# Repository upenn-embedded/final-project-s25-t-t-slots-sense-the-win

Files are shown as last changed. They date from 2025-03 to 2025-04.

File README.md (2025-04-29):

Review Assignment Due Date (https://classroom.github.com/a/WXeqVgks)

# final-project-skeleton

* Team Number: 6
* Team Name: T&T Slots - Sense the Win
* Team Members: Theodor Bulacovschi, Yiding Tian
* GitHub Repository URL: [https://github.com/upenn-embedded/final-project-s25-t-t-slots-sense-the-win](https://github.com/upenn-embedded/final-project-s25-t-t-slots-sense-the-win)
* GitHub Pages Website URL: [for final submission]

## Final Project Proposal

### 1. Abstract

*In a few sentences, describe your final project.*

Our project is an interactive chance-based gaming device that takes into account the player's vital signs to adjust the probability of winning, maximizing engagement and retention. In lay-man's terms, it's a slot machine that measures the user's pulse and changes the odds to keep them playing longer.

### 2. Motivation

*What is the problem that you are trying to solve? Why is this project interesting? What is the intended purpose?*

Considering the abundance of health-tracking initiatives, we thought of making a unique device, merging entertainment and bio-monitoring. This device would also be useful as a case study for the efficiency of variable-odds gaming devices, and the effects on the users.

### 3. System Block Diagram

*Show your high level design, as done in WS1 and WS2. What are the critical components in your system? How do they communicate (I2C?, interrupts, ADC, etc.)? What power regulation do you need?*

Motors for actual slot machine wheels are optional, and they would require extra power beyond what the AtMega can provide. However, their implementation would not be that difficult, considering the power circuitry already identified for WS1.

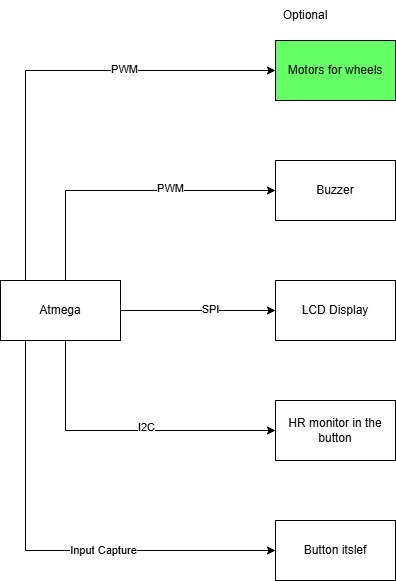
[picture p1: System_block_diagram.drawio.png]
Diagram


### 4. Design Sketches

*What will your project look like? Do you have any critical design features? Will you need any special manufacturing techniques to achieve your vision, like power tools, laser cutting, or 3D printing?*

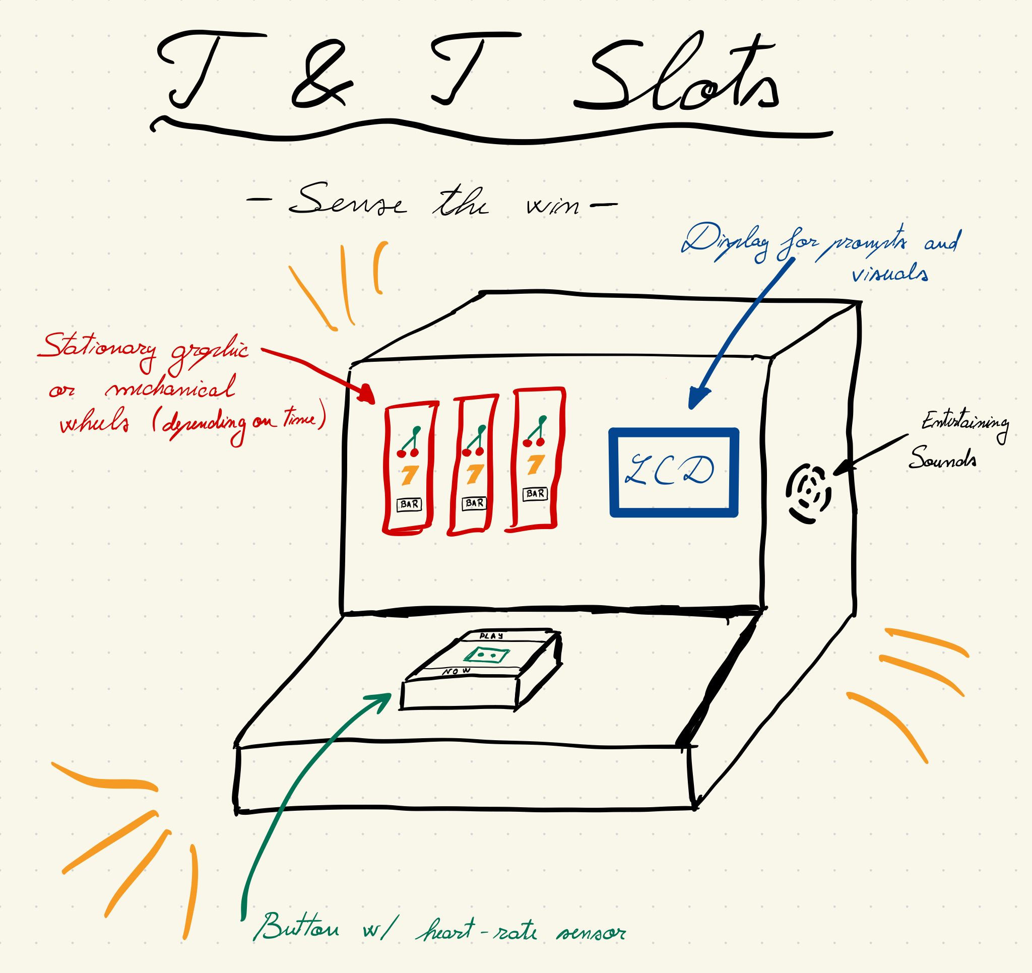
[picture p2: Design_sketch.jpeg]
Design_sketch


### 5. Software Requirements Specification (SRS)

*Formulate key software requirements here. Think deeply on the design: What must your device do? How will you measure this during validation testing? Create 4 to 8 critical system requirements.*

*These must be testable! See the Final Project Manual Appendix for details. Refer to the table below; replace these examples with your own.*

**5.1 Definitions, Abbreviations**

Here, you will define any special terms, acronyms, or abbreviations you plan to use for hardware

HR - heart rate

**5.2 Functionality**

| ID | Description |
| --- | --- |
| SRS-01 | The ATmega shall continuously prompt the user to play, telling them to keep their hand pressing the button until the HR sensor establishes their pulse. |
| SRS-02 | The HR sensor shall be measuring only while the button is pressed, to conceal its existance. |
| SRS-03 | Upon button release, the ATmega shall change the odds in the following manner: if the HR is low, increase odds of winning to increase excitement, HR, and engagement. If HR is high, decrease odds to elongate play, build anticipation, and increase profits. |
| SRS-04 | The buzzer shall play varied exciting tunes, encouraging continued play, and shall react to game outcomes. |
| SRS-05 | If implemented, the wheels should begin spinning on button press, and sequentially stop after the button release, according to the game outcome. |

### 6. Hardware Requirements Specification (HRS)

*Formulate key hardware requirements here. Think deeply on the design: What must your device do? How will you measure this during validation testing? Create 4 to 8 critical system requirements.*

*These must be testable! See the Final Project Manual Appendix for details. Refer to the table below; replace these examples with your own.*

**6.1 Definitions, Abbreviations**

Here, you will define any special terms, acronyms, or abbreviations you plan to use for hardware

**6.2 Functionality**

| ID | Description |
| --- | --- |
| HRS-01 | A heart rate monitor shall be used for monitoring user vital signs. It should be able to measure HR in the range 50-180 BPM. |
| HRS-02 | A buzzer shall be able play various sound frequencies and patterns in a pleasant manner. |
| HRS-03 | A display shall be able to display prompts, information and potentially animations to the user. |
| HRS-04 | A button shall be made big enough to conceal the HR sensor, while being transparent in the region required for measurements. |
| HRS-05 | If implemented, the motors spinning the slot wheels should have variable speed, make the clicking sounds specific to slot machines, and be able to stop at precises positions according to the game outcome. |

### 7. Bill of Materials (BOM)

*What major components do you need and why? Try to be as specific as possible. Your Hardware & Software Requirements Specifications should inform your component choices.*

*In addition to this written response, copy the Final Project BOM Google Sheet and fill it out with your critical components (think: processors, sensors, actuators). Include the link to your BOM in this section.*

[https://docs.google.com/spreadsheets/d/1qyvZnWI3Nq7rkF-FLIlKeIRL2Z1_xs5uF36gUQWZ2QY/edit?usp=sharing](https://docs.google.com/spreadsheets/d/1qyvZnWI3Nq7rkF-FLIlKeIRL2Z1_xs5uF36gUQWZ2QY/edit?usp=sharing)

### 8. Final Demo Goals

*How will you demonstrate your device on demo day? Will it be strapped to a person, mounted on a bicycle, require outdoor space? Think of any physical, temporal, and other constraints that could affect your planning.*

It will be on a table. We will have well-rested (calm heart rate) players play, then do jumping jacks to elevate the players heart rate and see the different effects on the outcomes of the slot machine.

### 9. Sprint Planning

*You've got limited time to get this project done! How will you plan your sprint milestones? How will you distribute the work within your team? Review the schedule in the final project manual for exact dates.*

| Milestone  | Functionality Achieved | Distribution of Work |
| --- | --- | --- |
| Sprint #1  | Display prompts on LCD | 50%, details TBD |
| Sprint #2  | Communicate over I2C with HR sensor | 50%, details TBD |
| MVP Demo | Continuous HR values, Display game outcomes | 50%, details TBD |
| Final Demo | HR monitor only when button is pressed, variable odds, animations, sound | 50%, details TBD |

**This is the end of the Project Proposal section. The remaining sections will be filled out based on the milestone schedule.**

## Sprint Review #1

### Last week's progress
Just Started

### Current state of project
Wrote code for displaying prompts. Implemented the basic game stages and state machine. Designed GUI for the game. Drew animations on screen. 
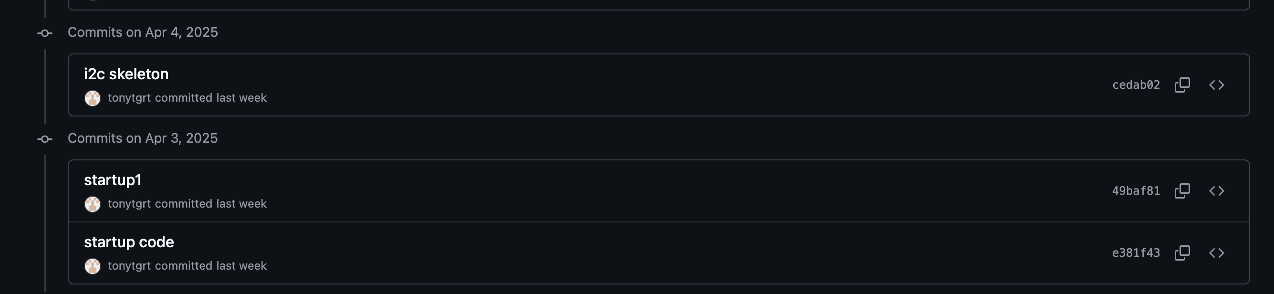
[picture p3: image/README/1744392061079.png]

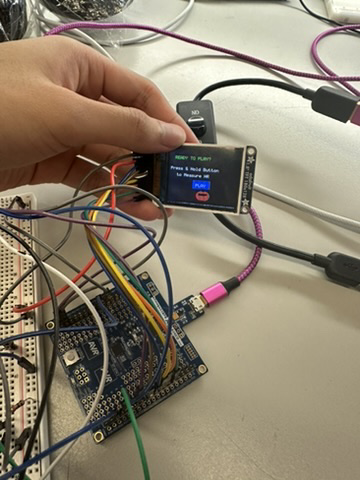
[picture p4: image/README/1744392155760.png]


### Next week's plan
Configure I2C connection of HR sensor. Figure out how to integrate the sensor with the button.

## Sprint Review #2

### Last week's progress
I2C testing on HR sensor mostly completed. Compatible buttons arrived. Worked on drilling holes and integrating the button with the sensor. 

### Current state of project
Close to MVP. HR sensor is configured on an individual profile. Button and sensor is about to get integrated together. 
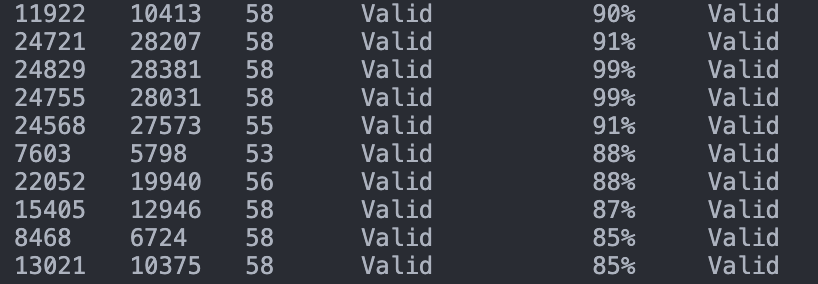
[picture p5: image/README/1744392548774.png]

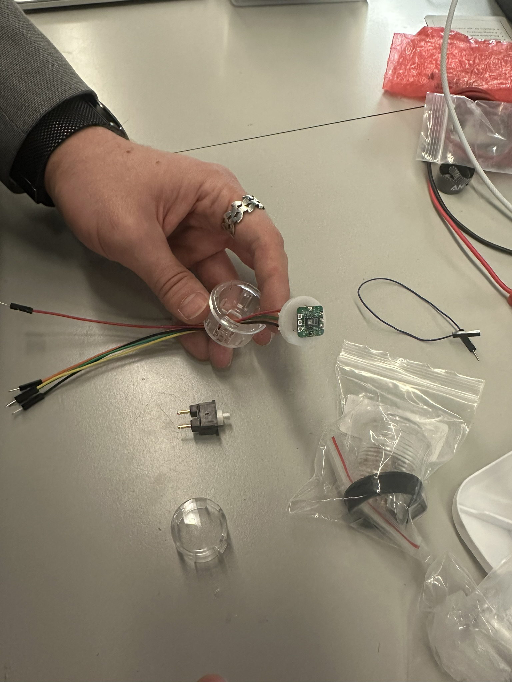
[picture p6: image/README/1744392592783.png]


### Next week's plan
Integrate the HR sensor driver code to the main game project. Integrate the button and sensor in hardware.

## MVP Demo

1. Show a system block diagram & explain the hardware implementation.

- Same diagram without the optional wheel part

- Diagram

2. Explain your firmware implementation, including application logic and critical drivers you've written.

- We implemented our firmware with our own I2C driver explicitly for the MAX30102 heart rate sensor. We used the LCD driver library as implemented in Lab 4, and the uart library as provided before. The firmware measures the heartrate continuously, and sets up the game stages based on the button press. Different stages are outputted to the LCD screen along with different sound effects by the buzzer. 

3. Demo your device.

- Demoed to James
- 

4. Have you achieved some or all of your Software Requirements Specification (SRS)?
- Achieved all but the optional motor SRS-05 and the SRS-02: *The HR sensor shall be measuring only while the button is pressed, to conceal its existance*. This requirement had some oversight that since the LED on the sensor is always on it becomes irrelevent to try to conceal on the software level.
- Showed the data and outcome to James.

5. Have you achieved some or all of your Hardware Requirements Specification (HRS)?
- Achieved all but the optional motor HRS-05.
- Showed the data and outcome to James.

6. Show off the remaining elements that will make your project whole: mechanical casework, supporting graphical user interface (GUI), web portal, etc.
- Will get a new wooden panel for holding the button
- Will glue the enclosure together, but might keep the tapes as an aethetic feature.
- Will tune the GUI animations and the sound effects for better entertainment

7. What is the riskiest part remaining of your project?
- Getting the new panel
   1. How do you plan to de-risk this?
   - Finding a bettern cutting station than the RPL
8. What questions or help do you need from the teaching team?

## Final Project Report

Don't forget to make the GitHub pages public website!
If you’ve never made a GitHub pages website before, you can follow this webpage (though, substitute your final project repository for the GitHub username one in the quickstart guide):  [https://docs.github.com/en/pages/quickstart](https://docs.github.com/en/pages/quickstart)

### 1. Video

[Insert final project video here]

* The video must demonstrate your key functionality.
* The video must be 5 minutes or less.
* Ensure your video link is accessible to the teaching team. Unlisted YouTube videos or Google Drive uploads with SEAS account access work well.
* Points will be removed if the audio quality is poor - say, if you filmed your video in a noisy electrical engineering lab.

### 2. Images

[Insert final project images here]

*Include photos of your device from a few angles. If you have a casework, show both the exterior and interior (where the good EE bits are!).*

### 3. Results

*What were your results? Namely, what was the final solution/design to your problem?*

#### 3.1 Software Requirements Specification (SRS) Results

*Based on your quantified system performance, comment on how you achieved or fell short of your expected requirements.*

*Did your requirements change? If so, why? Failing to meet a requirement is acceptable; understanding the reason why is critical!*

*Validate at least two requirements, showing how you tested and your proof of work (videos, images, logic analyzer/oscilloscope captures, etc.).*

| ID | Description | Validation Outcome |
| --- | --- | --- |
| SRS-01 | The ATmega shall continuously prompt the user to play, telling them to keep their hand pressing the button until the HR sensor establishes their pulse. | Confirmed. The LCD display will show up a prompt screen when the sensor have not obtained a heart rate reading. |
| SRS-02 | The HR sensor shall be measuring only while the button is pressed, to conceal its existance |Deprecated. This SRS becomes irrelevant since the button is transparent and sensor is clearly visible, there's no point in hiding the sensor's existence from software level. | 
| SRS-03 | Upon button release, the ATmega shall change the odds in the following manner: if the HR is low, increase odds of winning to increase excitement, HR, and engagement. If HR is high, decrease odds to elongate play, build anticipation, and increase profits. | Confirmed. The determineWinOdds() function will change the odds accordingly and print winning odds to uart. |
| SRS-04 | The buzzer shall play varied exciting tunes, encouraging continued play, and shall react to game outcomes. | Confirmed. The buzzer plays various exciting and engaging tones in different stages of gameplay. |
| SRS-05 | If implemented, the wheels should begin spinning on button press, and sequentially stop after the button release, according to the game outcome.| Not implemented. |

SRS-03 UART result sample
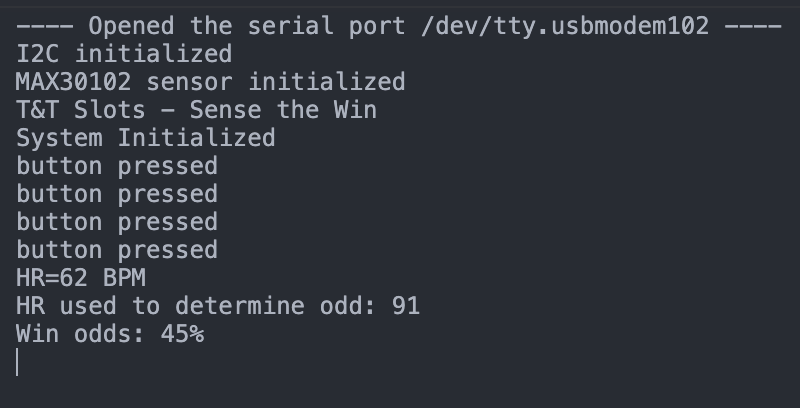
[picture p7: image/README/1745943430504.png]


#### 3.2 Hardware Requirements Specification (HRS) Results

*Based on your quantified system performance, comment on how you achieved or fell short of your expected requirements.*

*Did your requirements change? If so, why? Failing to meet a requirement is acceptable; understanding the reason why is critical!*

*Validate at least two requirements, showing how you tested and your proof of work (videos, images, logic analyzer/oscilloscope captures, etc.).*

| ID | Description | Validation Outcome |
| --- | --- | --- |
| HRS-01 |A heart rate monitor shall be used for monitoring user vital signs. It should be able to measure HR in the range 50-180 BPM. | Partly Confirmed. The sensor is able to measure HR at least 50-120 BPM.|
| HRS-02 | A buzzer shall be able play various sound frequencies and patterns in a pleasant manner. | Confirmed. The buzzer is able to play various sound. |
| HRS-03 | A display shall be able to display prompts, information and potentially animations to the user. | Confirmed. The display is able to play prompts, results, and animations. |
| HRS-04 | A button shall be made big enough to conceal the HR sensor, while being transparent in the region required for measurements. | Confirmed. A button is customly made to fit in the heart rate sensor, although not fulling concealling since the heart rate sensor can only work under transparent topping. |
| HRS-05 | If implemented, the motors spinning the slot wheels should have variable speed, make the clicking sounds specific to slot machines, and be able to stop at precises positions according to the game outcome. | Not implemented. |

HRS-01
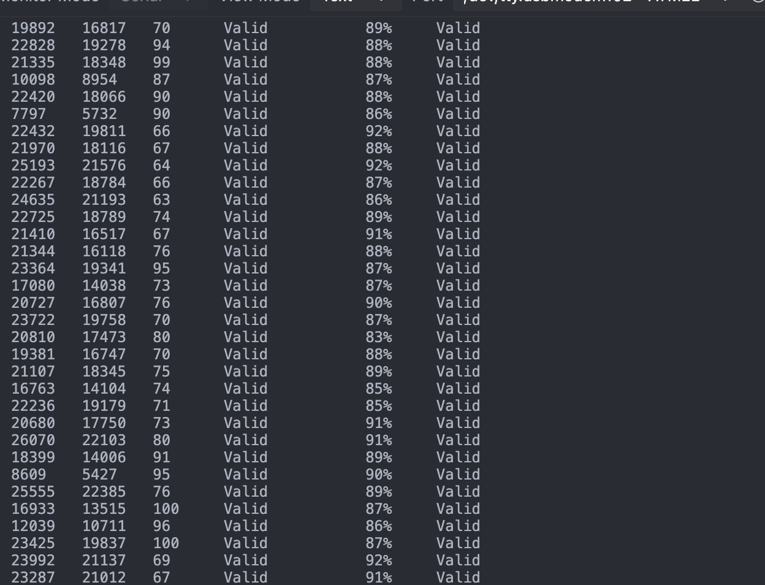
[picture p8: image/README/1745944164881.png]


### 4. Conclusion

Reflect on your project. Some questions to address:

* What did you learn from it?
   * I2C communication library writing.
   * Mechanical customization for tight hardware integration.
* What went well?
   * Pretty much everything.
* What accomplishments are you proud of?
   * Beautifully engineered button with integrated sensor.
* What did you learn/gain from this experience?
   * I2C communication library writing.
   * Mechanical customization for tight hardware integration.
* Did you have to change your approach?
   * No
* What could have been done differently?
   * The results could have been driven by motors and mechanical wheels if we had more time.
* Did you encounter obstacles that you didn’t anticipate?
   * No.
* What could be a next step for this project?
   * Find a way to integrate a mechanical wheel for the spinning.

## References

Fill in your references here as you work on your final project. Describe any libraries used here.

* LCD SPI library for Lab 4, as implemented by Yiding Tian.

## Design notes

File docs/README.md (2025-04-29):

# Final Report

## Video

{% include youtube.html id="CNu7HjIhgl4" %}

### Images

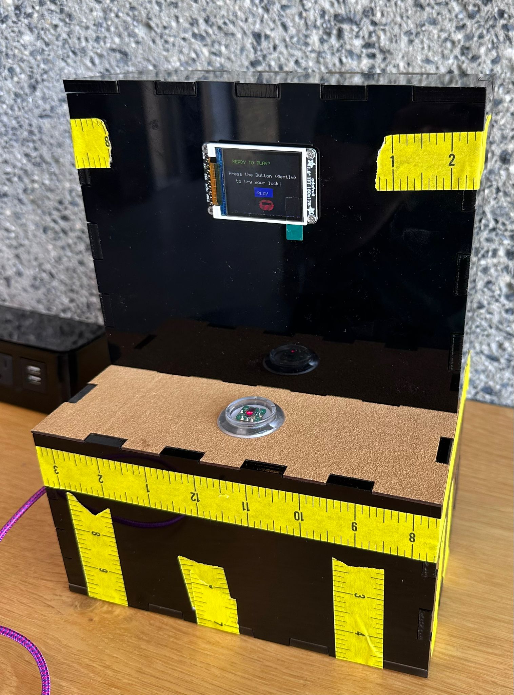
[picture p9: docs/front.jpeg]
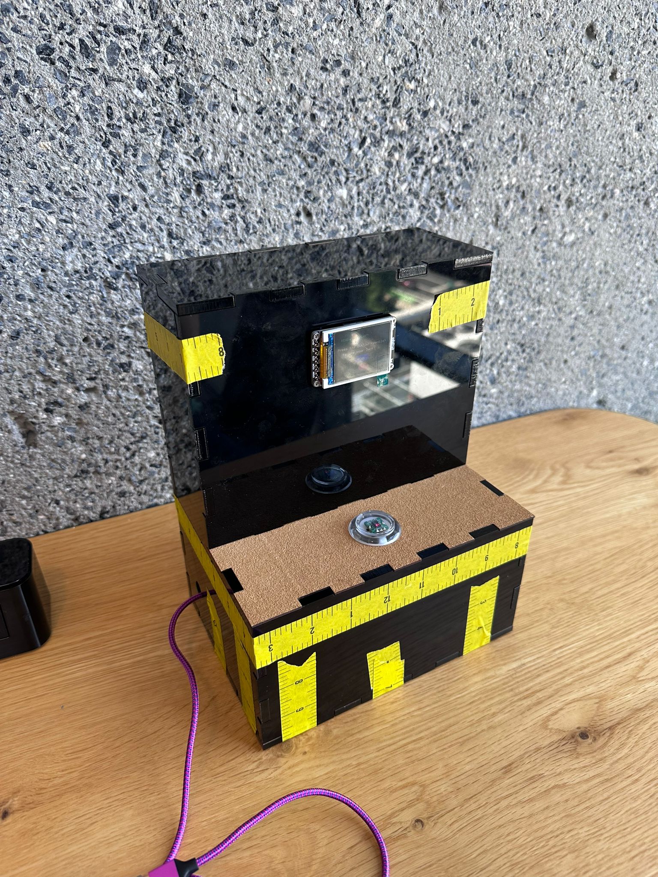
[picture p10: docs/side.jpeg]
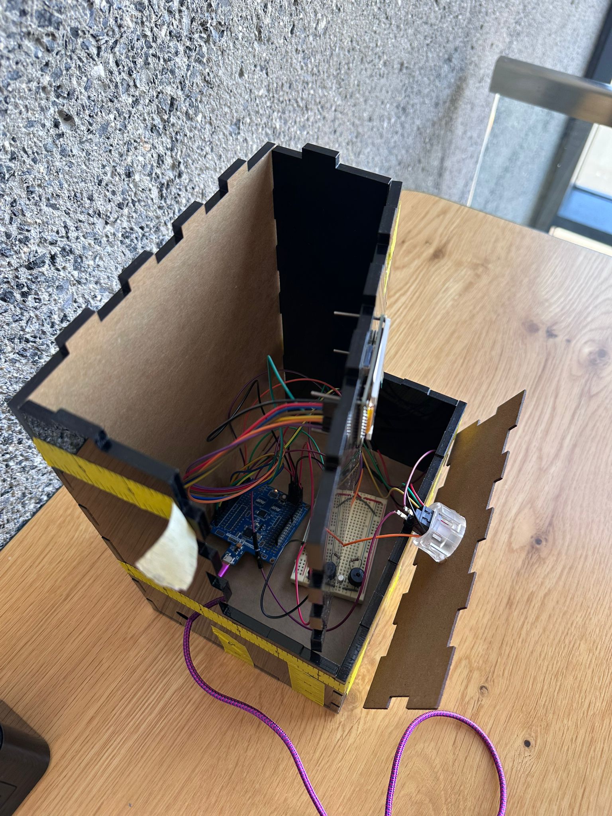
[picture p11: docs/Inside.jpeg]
|  |  |  |
| - | - | - |
| Front | Side | Inside |

### SRS Validation

| ID | Description | Validation Outcome |
| --- | --- | --- |
| SRS-01 | The ATmega shall continuously prompt the user to play, telling them to keep their hand pressing the button until the HR sensor establishes their pulse. | Confirmed. The LCD display will show up a prompt screen when the sensor have not obtained a heart rate reading. |
| SRS-02 | The HR sensor shall be measuring only while the button is pressed, to conceal its existance | Deprecated for reliability. We also noticed during demo days that even though people knew the slot machine was unfair, and they saw their HR was measured constantly, they would still play. |
| SRS-03 | Upon button release, the ATmega shall change the odds in the following manner: if the HR is low, increase odds of winning to increase excitement, HR, and engagement. If HR is high, decrease odds to elongate play, build anticipation, and increase profits. | Confirmed. The determineWinOdds() function will change the odds accordingly and print winning odds to uart. See the code below. |
| SRS-04 | The buzzer shall play varied exciting tunes, encouraging continued play, and shall react to game outcomes. | Confirmed. The buzzer plays various exciting and engaging tones in different stages of gameplay. This can be seen in the video |
| SRS-05 | If implemented, the wheels should begin spinning on button press, and sequentially stop after the button release, according to the game outcome. | Not implemented. |

**SRS-03** :

```c
// Determine win odds based on heart rate
uint8_t determineWinOdds() {
    // Win logic according to SRS-03:
    // If HR is low, increase odds of winning
    // If HR is high, decrease odds to elongate play
  
    // Define heart rate thresholds
    #define LOW_HR_THRESHOLD 80
    #define HIGH_HR_THRESHOLD 120
  
    uint8_t winPercentage = 100;
  
    printf("HR used to determine odd: %u\n", heartRate);
  
    if (heartRate < LOW_HR_THRESHOLD) {
        // Low heart rate - guarantee win 
        winPercentage = 100;
    } else if (heartRate > HIGH_HR_THRESHOLD) {
        // High heart rate - lower odds (down to 5%)
        winPercentage = 20 - ((heartRate - HIGH_HR_THRESHOLD) / 10);
        if (winPercentage < 5) winPercentage = 5;
    } else {
        // Medium heart rate - medium odds (10-20%)
        winPercentage = 50 - ((heartRate - LOW_HR_THRESHOLD) / 2);
    }
  
    printf("Win odds: %u%%\r\n", winPercentage);
    return winPercentage;
}
```



Our final design satisfies most of our SRSs, with some omissions where the required timeline or user testing informed our decision to not implement certain extra features or stray from our initial thoughts of what the project should look like. Overall, our SRSs did help guide our progress, and this is definitely a technique we will use in future projects as well.

### HRS Validation

| ID | Description | Validation Outcome |
| --- | --- | --- |
| HRS-01 | A heart rate monitor shall be used for monitoring user vital signs. It should be able to measure HR in the range 50-180 BPM. | Partly Confirmed. The sensor is able to measure HR at least 50-120 BPM. None of us took the slot machine to the gym with us to test the bounds. |
| HRS-02 | A buzzer shall be able play various sound frequencies and patterns in a pleasant manner. | Confirmed. The buzzer is able to play various sound. See pictures below |
| HRS-03 | A display shall be able to display prompts, information and potentially animations to the user. | Confirmed. The display is able to play prompts, results, and animations. See demo video. |
| HRS-04 | A button shall be made big enough to conceal the HR sensor, while being transparent in the region required for measurements. | Confirmed. A button is customly made to fit in the heart rate sensor, although not fulling concealling since the heart rate sensor can only work under transparent topping. See pictures. |
| HRS-05 | If implemented, the motors spinning the slot wheels should have variable speed, make the clicking sounds specific to slot machines, and be able to stop at precises positions according to the game outcome. | Not implemented. |

**HRS-01** - 

**HRS-02** -

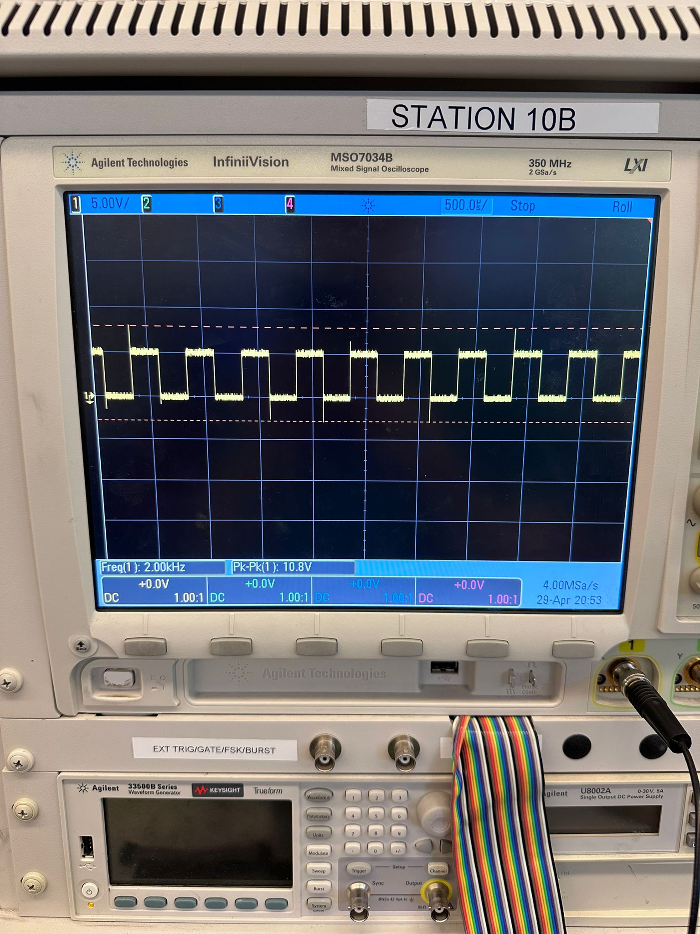
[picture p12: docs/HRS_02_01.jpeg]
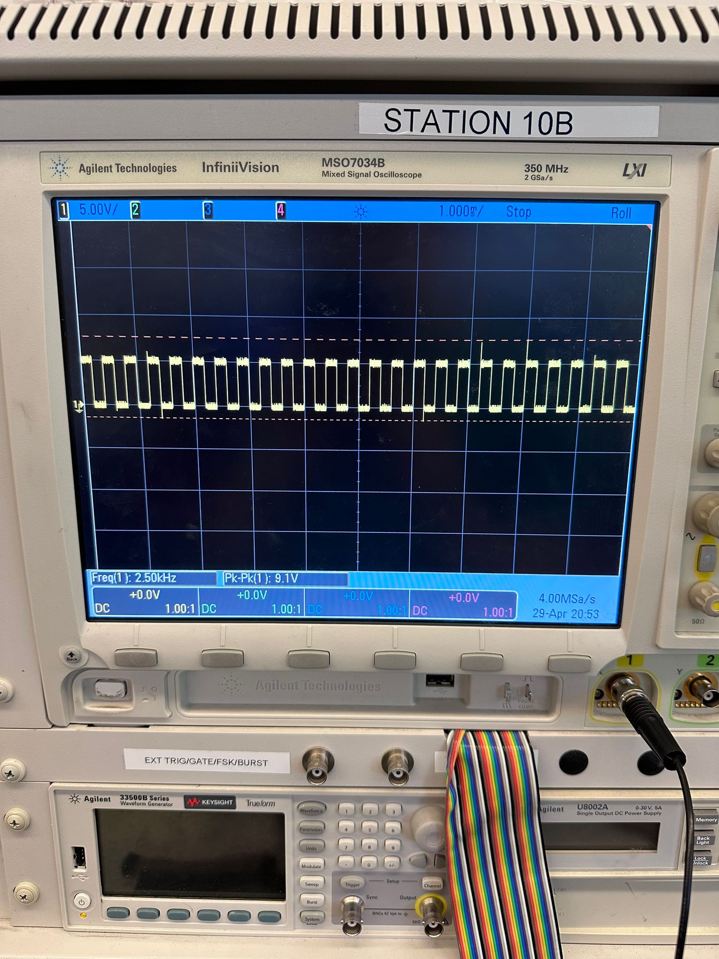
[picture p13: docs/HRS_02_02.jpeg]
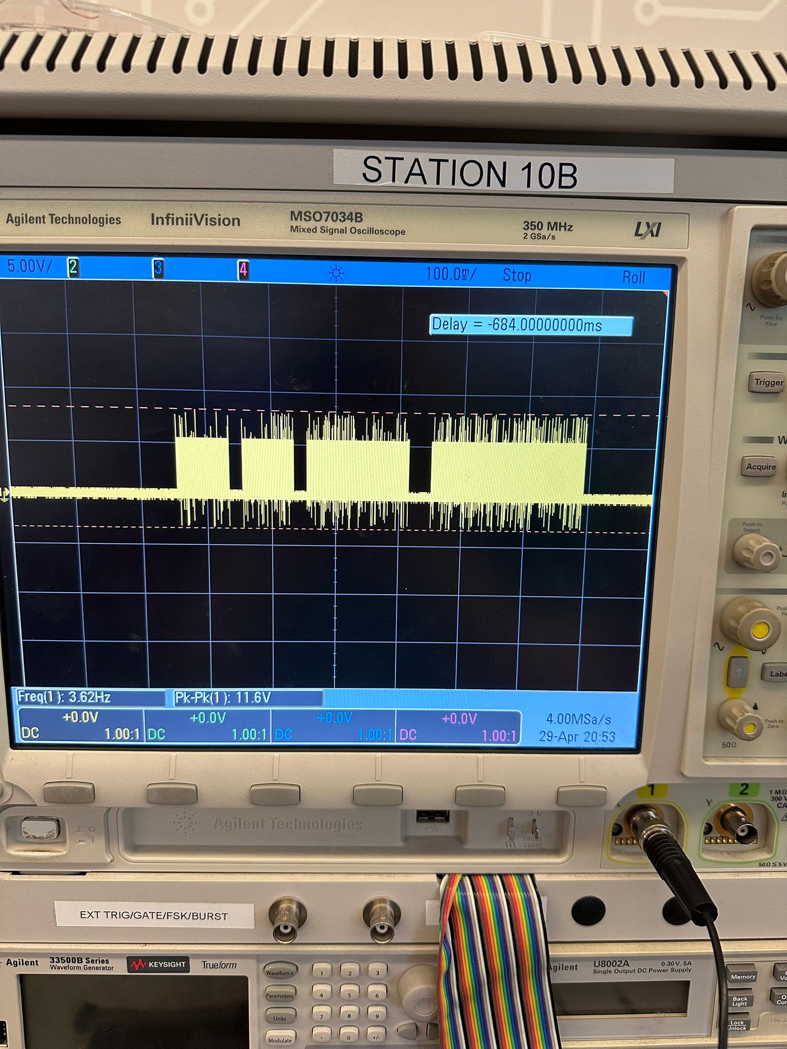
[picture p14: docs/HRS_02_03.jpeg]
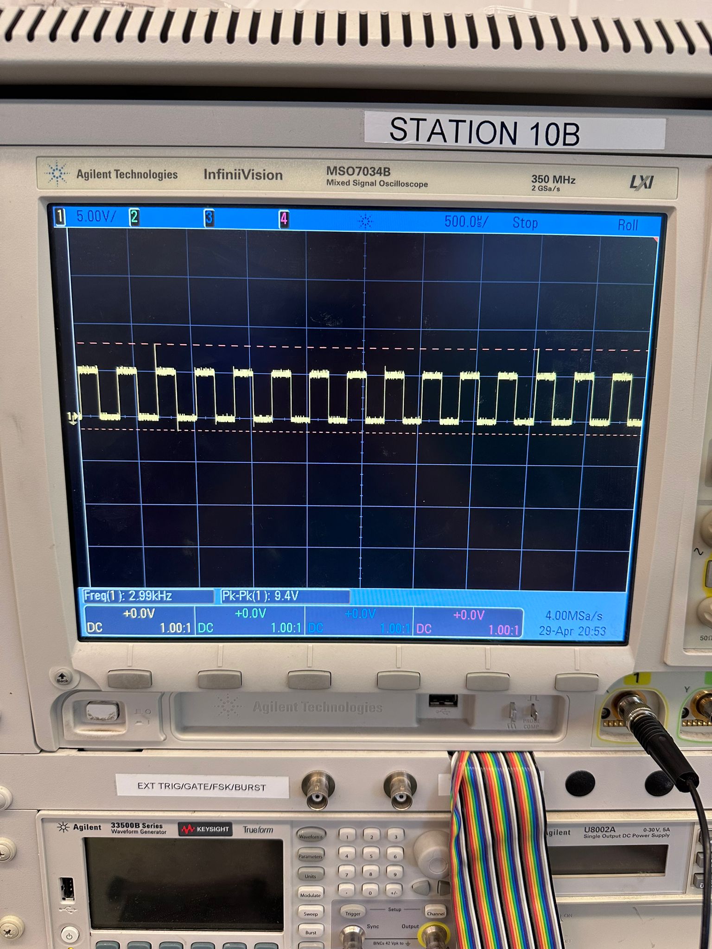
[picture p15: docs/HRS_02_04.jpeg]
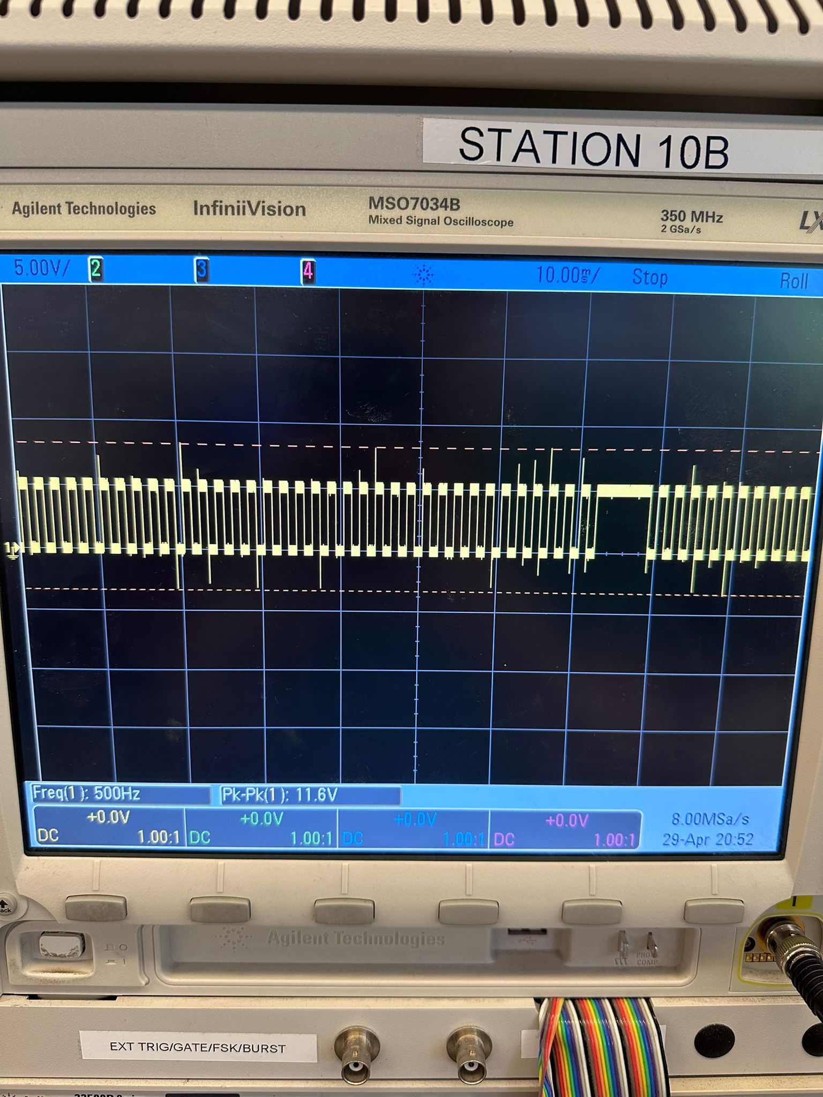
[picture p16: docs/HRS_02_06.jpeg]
|  |  |  |  |  |
| :---: | :---: | :---: | :---: | :---: |
| 2kHz | 2.5kHz | Multiple Sounds | 3kHz | 500Hz |

**HRS-04** -

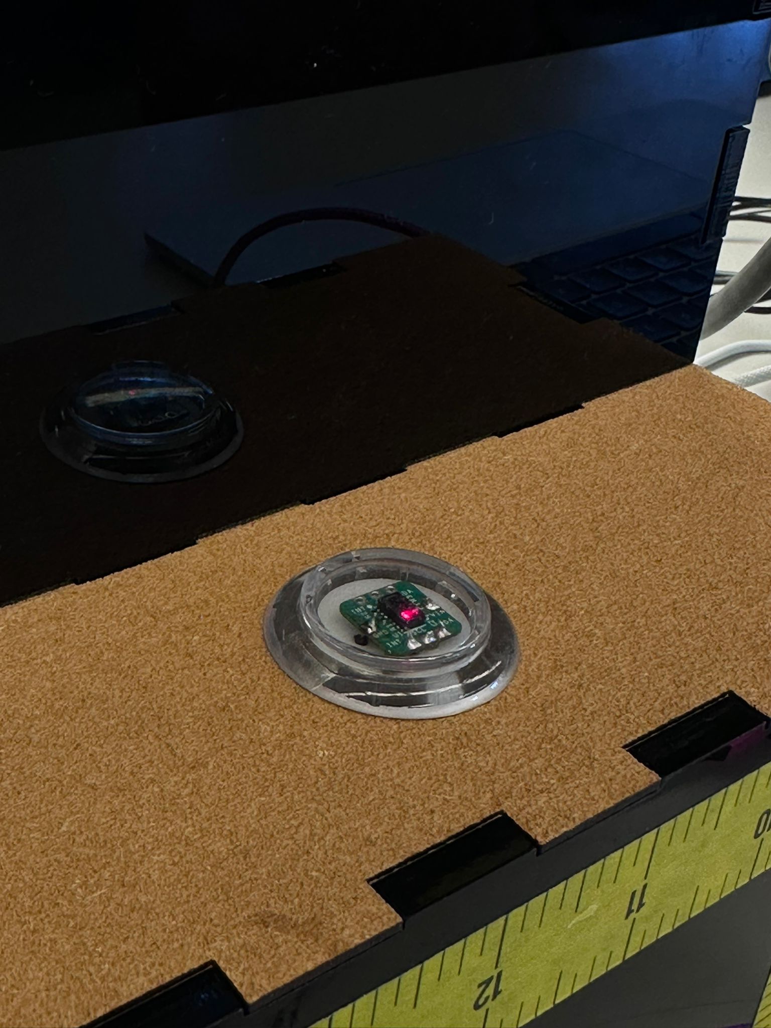
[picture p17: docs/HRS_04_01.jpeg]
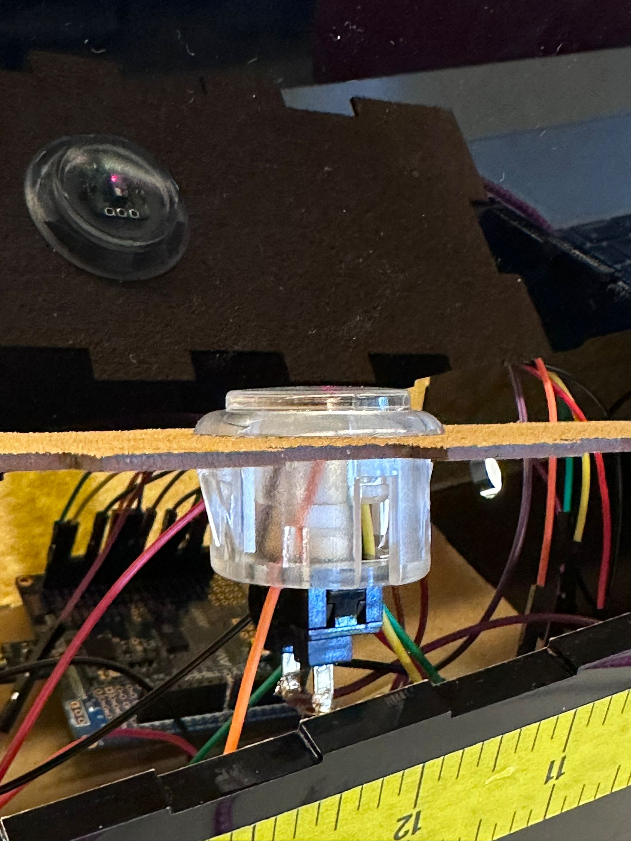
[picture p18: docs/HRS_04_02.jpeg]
|  |  |
| :---: | :---: |
| Top view | Side view |

Our final design satisfies most of our HRSs, with only one omissions where the required timeline informed our decision to not implement certain extra features. Validation for certain numerical values also proved difficult because of biological constrains of healthy humans, but overall, our HRSs did help guide our progress, and this is definitely a technique we will use in future projects as well.

### Conclusions

**Tony:** I learnt a lot writing the firmware of our slot machine, especially when writing the I2C driver for the heart rate sensor. The first approach to "reverse engineer" James' i2c.h provided in the worksheet before did not work quite so well, so I went back and wrote everything from scratch. I first wrote the driver in its standalone package, then integrated with the main gameplay code. Everything else went on pretty smooth for me in the firmware side. I will carry on this experience developing a driver for peripherals into my future projects.

**Theodor:** My experience with this project was really good. It felt great to see our device come together and bring excitement and entertainment to our friends and colleagues. I specifically learned more about how to mechanically customize hardware to get the most out of it. Most things went well, as we planned for mechanical and hardware failures by ordering multiple parts. I am particularly proud of the enclosure, the tactile plate, and the integrated button.

### References

* LCD SPI library for Lab 4, as implemented by Yiding Tian.
* UART library from UPenn Embedded

### Conclusion

Reflect on your project. Some questions to address:

* What did you learn from it?
  * I2C communication library writing.
  * Mechanical customization for tight hardware integration.
* What went well?
  * Pretty much everything.
* What accomplishments are you proud of?
  * Beautifully engineered button with integrated sensor.
* What did you learn/gain from this experience?
  * I2C communication library writing.
  * Mechanical customization for tight hardware integration.
* Did you have to change your approach?
  * No
* What could have been done differently?
  * The results could have been driven by motors and mechanical wheels if we had more time.
* Did you encounter obstacles that you didn’t anticipate?
  * No.
* What could be a next step for this project?
  * Find a way to integrate a mechanical wheel for the spinning.

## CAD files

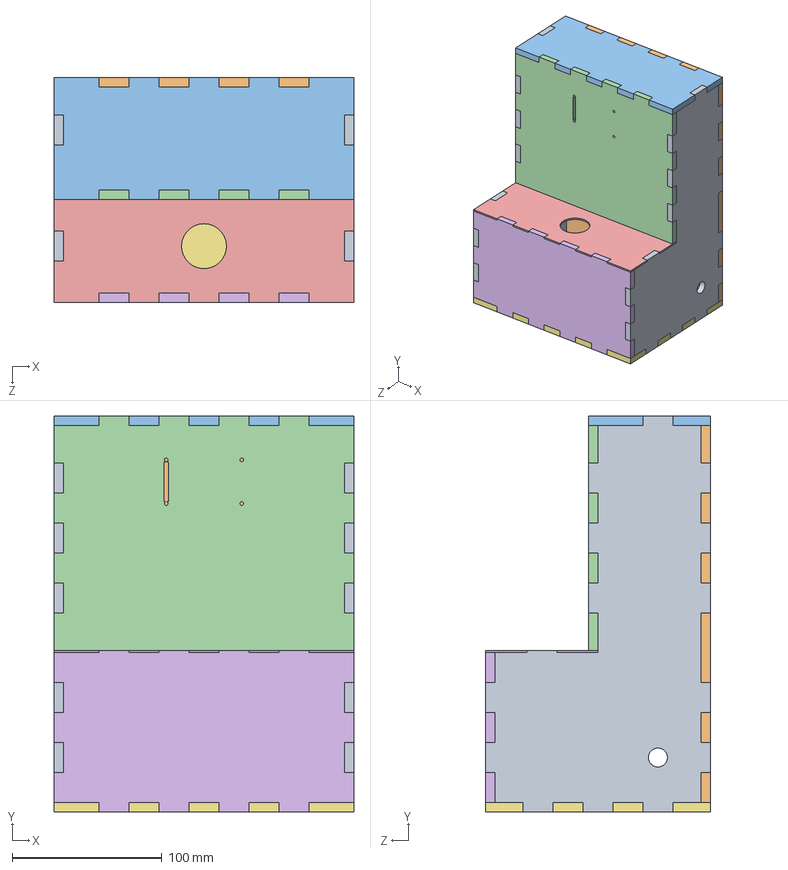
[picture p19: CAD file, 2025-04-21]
CAD/Slot_machine.SLDASM
200.0 x 264.3 x 150.0 mm
Bottom
Front_low
Button_plate
Front_high
Top
Back
Side x 2

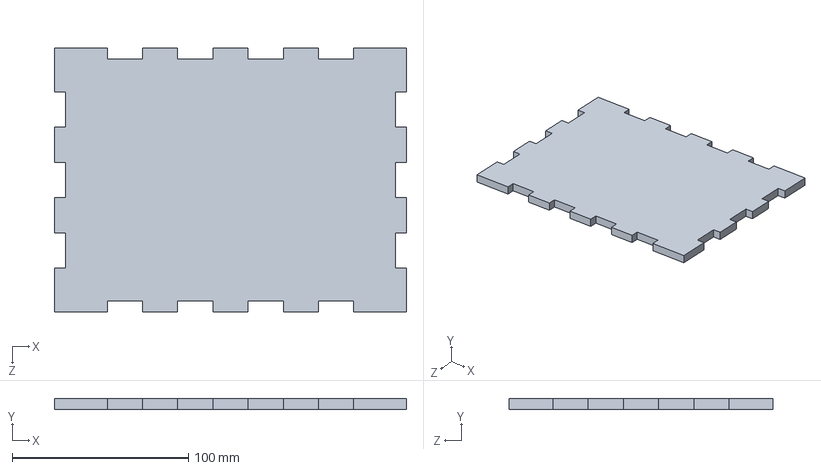
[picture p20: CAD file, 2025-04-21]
CAD/Bottom.SLDPRT
200.0 x 6.35 x 150.0 mm

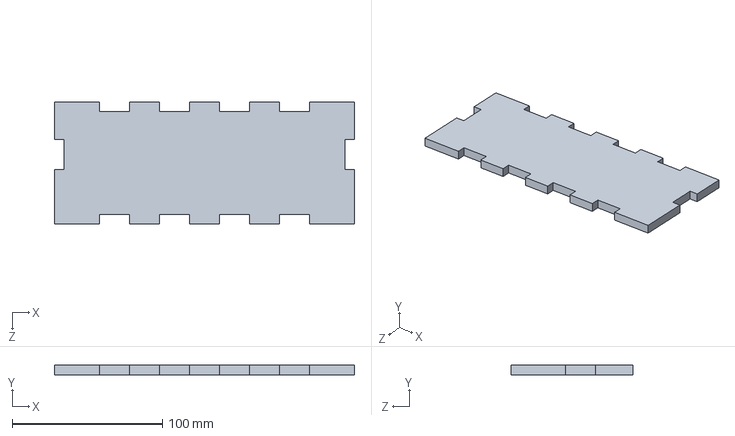
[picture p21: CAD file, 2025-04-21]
CAD/Top.SLDPRT
200.0 x 6.35 x 81.4 mm

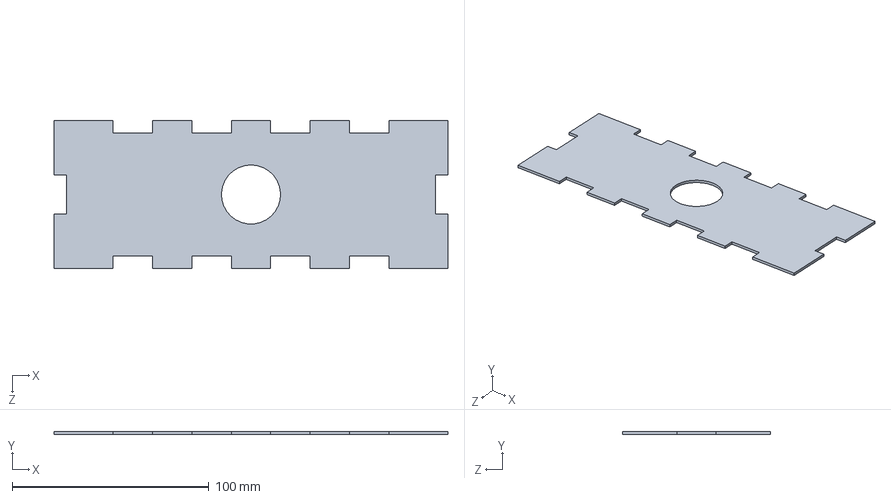
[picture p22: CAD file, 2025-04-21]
CAD/Button_plate.SLDPRT
200.0 x 1.59 x 75.0 mm

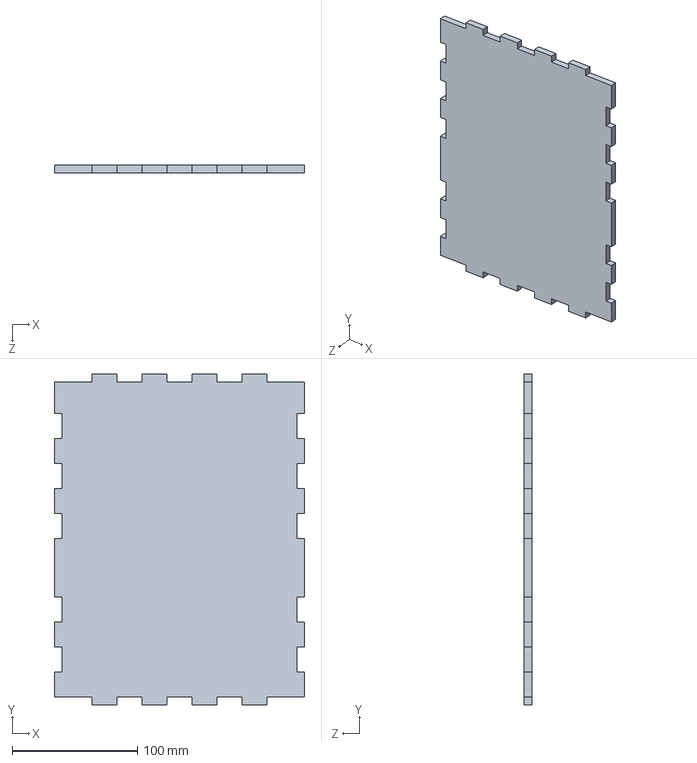
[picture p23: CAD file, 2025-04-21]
CAD/Back.SLDPRT
200.0 x 264.3 x 6.35 mm

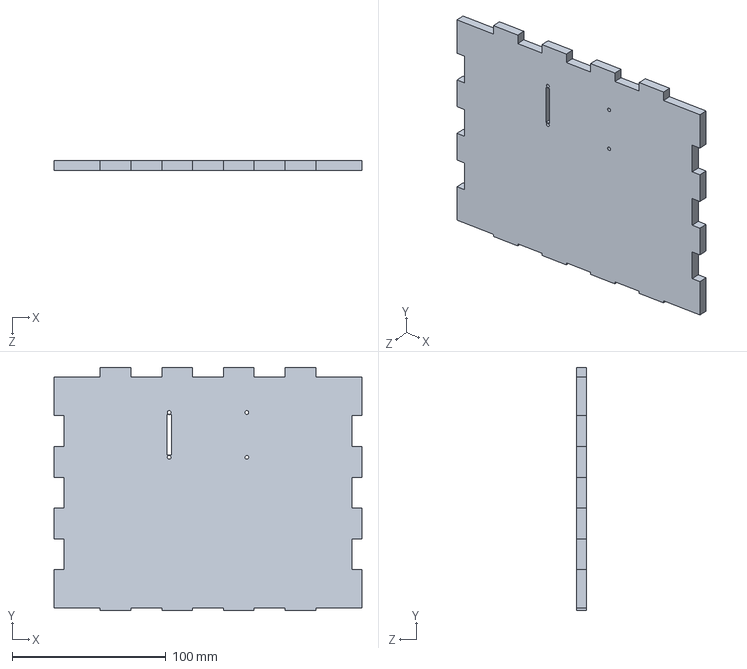
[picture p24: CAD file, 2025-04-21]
CAD/Front_high.SLDPRT
200.0 x 157.9 x 6.35 mm

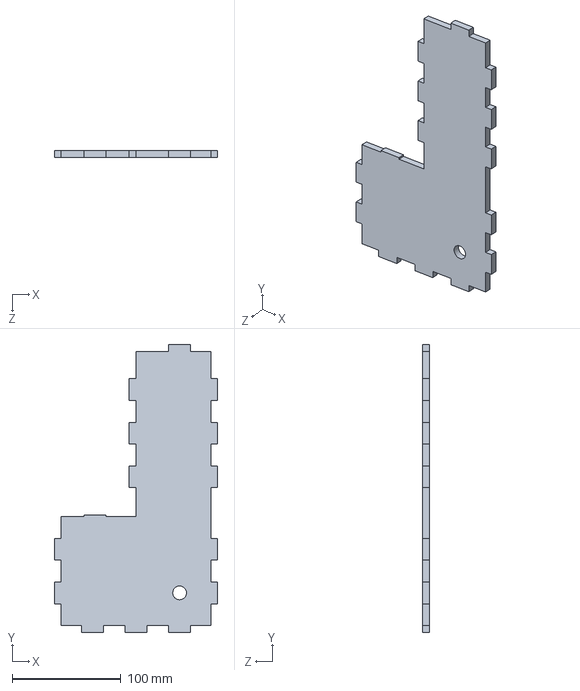
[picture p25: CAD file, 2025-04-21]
CAD/Side.SLDPRT
150.0 x 264.3 x 6.35 mm

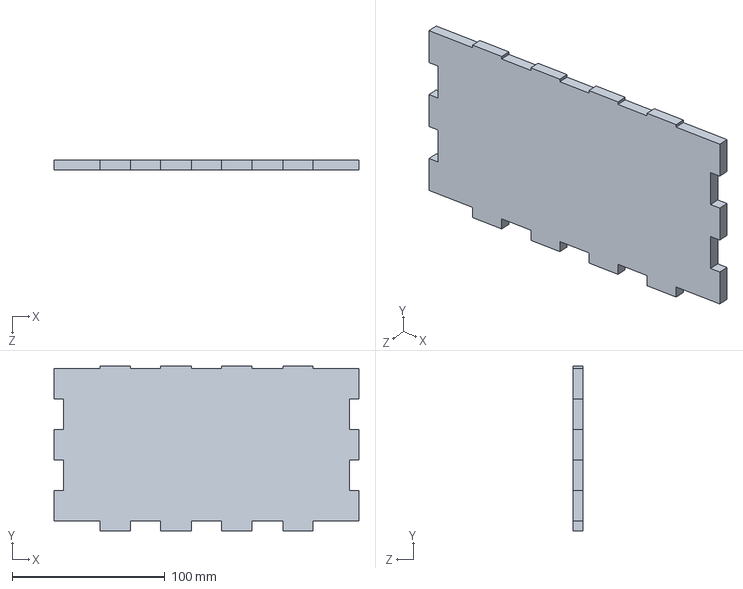
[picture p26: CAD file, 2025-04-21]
CAD/Front_low.SLDPRT
200.0 x 107.9 x 6.35 mm

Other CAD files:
CAD/Back.DWG
CAD/Bottom.DWG
CAD/Button_plate.DWG
CAD/Button_plate.STL
CAD/Front_high.DWG
CAD/Front_low.DWG
CAD/Side.DWG
CAD/Top.DWG

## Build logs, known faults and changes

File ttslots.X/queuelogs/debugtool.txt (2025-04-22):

1275 1745338438521 GEN4_TO_CONTROLLER_LOG:GEN4_PROGRAM_INT_LOG_ATmega328PB Pre:endOfOperations
1275 1745338438521 GEN4_TO_CONTROLLER_LOG:GEN4_PROGRAM_INT_LOG_ATmega328PB Payload
1275 1745338438521 GEN4_TO_CONTROLLER_LOG:GEN4_PROGRAM_INT_LOG_ATmega328PB null
1275 1745338438521 GEN4_TO_CONTROLLER_LOG:GEN4_PROGRAM_INT_LOG_ATmega328PB Payload End
1275 1745338438521 pro JtagIce3 [0x11] <<< 11 01 01

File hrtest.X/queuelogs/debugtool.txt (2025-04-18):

1047 1744388675983 GEN4_TO_CONTROLLER_LOG:GEN4_PROGRAM_INT_LOG_ATmega328PB Pre:endOfOperations
1047 1744388675983 GEN4_TO_CONTROLLER_LOG:GEN4_PROGRAM_INT_LOG_ATmega328PB Payload
1047 1744388675983 GEN4_TO_CONTROLLER_LOG:GEN4_PROGRAM_INT_LOG_ATmega328PB null
1047 1744388675983 GEN4_TO_CONTROLLER_LOG:GEN4_PROGRAM_INT_LOG_ATmega328PB Payload End
1047 1744388675983 pro JtagIce3 [0x11] <<< 11 01 01

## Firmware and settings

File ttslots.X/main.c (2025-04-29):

#define F_CPU 16000000UL
#include <avr/io.h>
#include <math.h>
#include <util/delay.h>
#include <avr/interrupt.h>
#include "ST7735.h"
#include "LCD_GFX.h"
#include "uart.h"
#include "i2c.h"
#include "max30102.h"

// Custom RNG variables
static uint16_t rand_seed = 1;

// Define I2C frequency
#define I2C_FREQUENCY      400000UL  // 400kHz for MAX30102 communication

// Define the number of samples to read in each iteration
#define SAMPLE_COUNT       10

// Sample buffer
max30102_fifo_sample_t samples[SAMPLE_COUNT];

#define BUZZER_PIN PD5    // Buzzer connected to PD5/OC0B

// Define states for the slot machine
typedef enum {
    STATE_WELCOME,
    STATE_PRESS_BUTTON,
    STATE_MEASURING,
    STATE_SPINNING,
    STATE_RESULT
} SlotMachineState;

// Global variables
SlotMachineState currentState = STATE_WELCOME;
volatile uint8_t buttonPressed = 0;
uint8_t animationFrame = 0;
uint8_t measureAnime = 0;
max30102_result_t result;
volatile uint32_t heartRate;
volatile bool heartRateReady = false;
uint8_t sample_count;
uint8_t write_ptr, read_ptr, overflow;
uint8_t int_status_1, int_status_2;

// Function prototypes
void initialize(void);
void displayWelcomeScreen(void);
void displayPressButtonPrompt(void);
void displayMeasuringPrompt(void);
void displaySpinningPrompt(void);
void displayResultScreen(uint8_t win);
void setupButtonInterrupt(void);
uint8_t determineWinOdds(void);
uint16_t custom_rand(void);
uint16_t custom_rand_range(uint16_t max);

// Buzzer control functions
void init_buzzer() {
    // Set buzzer pin as output
    DDRD |= (1 << BUZZER_PIN);
}

// Play specific frequencies with fixed delays
void play_500hz(uint16_t duration_ms) {
    uint16_t cycles = duration_ms;  // Each cycle is about 1ms for 500Hz
    for (uint16_t i = 0; i < cycles; i++) {
        PORTD |= (1 << BUZZER_PIN);
        _delay_us(1000);  // Half period for 500Hz = 1000us
        PORTD &= ~(1 << BUZZER_PIN);
        _delay_us(1000);
    }
}

void play_1000hz(uint16_t duration_ms) {
    uint16_t cycles = duration_ms * 2;  // Each cycle is about 0.5ms for 1000Hz
    for (uint16_t i = 0; i < cycles; i++) {
        PORTD |= (1 << BUZZER_PIN);
        _delay_us(500);  // Half period for 1000Hz = 500us
        PORTD &= ~(1 << BUZZER_PIN);
        _delay_us(500);
    }
}

void play_1500hz(uint16_t duration_ms) {
    uint16_t cycles = duration_ms * 3;  // Each cycle is about 0.33ms for 1500Hz
    for (uint16_t i = 0; i < cycles; i++) {
        PORTD |= (1 << BUZZER_PIN);
        _delay_us(333);  // Half period for 1500Hz = 333us
        PORTD &= ~(1 << BUZZER_PIN);
        _delay_us(333);
    }
}

void play_2000hz(uint16_t duration_ms) {
    uint16_t cycles = duration_ms * 4;  // Each cycle is about 0.25ms for 2000Hz
    for (uint16_t i = 0; i < cycles; i++) {
        PORTD |= (1 << BUZZER_PIN);
        _delay_us(250);  // Half period for 2000Hz = 250us
        PORTD &= ~(1 << BUZZER_PIN);
        _delay_us(250);
    }
}

// Additional buzzer frequency functions
void play_750hz(uint16_t duration_ms) {
    uint16_t cycles = duration_ms * 1.5;  // Each cycle is about 0.67ms for 750Hz
    for (uint16_t i = 0; i 
            < cycles; i++) {
        PORTD |= (1 << BUZZER_PIN);
        _delay_us(667);  // Half period for 750Hz = 667us
        PORTD &= ~(1 << BUZZER_PIN);
        _delay_us(667);
    }
}

void play_1250hz(uint16_t duration_ms) {
    uint16_t cycles = duration_ms * 2.5;  // Each cycle is about 0.4ms for 1250Hz
    for (uint16_t i = 0; i < cycles; i++) {
        PORTD |= (1 << BUZZER_PIN);
        _delay_us(400);  // Half period for 1250Hz = 400us
        PORTD &= ~(1 << BUZZER_PIN);
        _delay_us(400);
    }
}

void play_2500hz(uint16_t duration_ms) {
    uint16_t cycles = duration_ms * 5;  // Each cycle is about 0.2ms for 2500Hz
    for (uint16_t i = 0; i < cycles; i++) {
        PORTD |= (1 << BUZZER_PIN);
        _delay_us(200);  // Half period for 2500Hz = 200us
        PORTD &= ~(1 << BUZZER_PIN);
        _delay_us(200);
    }
}

void play_3000hz(uint16_t duration_ms) {
    uint16_t cycles = duration_ms * 6;  // Each cycle is about 0.167ms for 3000Hz
    for (uint16_t i = 0; i < cycles; i++) {
        PORTD |= (1 << BUZZER_PIN);
        _delay_us(167);  // Half period for 3000Hz = 167us
        PORTD &= ~(1 << BUZZER_PIN);
        _delay_us(167);
    }
}

// Sound pattern functions
void play_welcome_theme(void) {
    play_1000hz(80);
    _delay_ms(20);
    play_1500hz(80);
    _delay_ms(20);
    play_2000hz(100);
    _delay_ms(30);
    play_2500hz(150);
}

void play_button_press(void) {
    play_1500hz(30);
    play_2000hz(20);
}

void play_measuring_sound(void) {
    play_750hz(30);
    _delay_ms(10);
    play_1000hz(30);
    _delay_ms(10);
    play_1250hz(30);
}

void play_spinning_sound(void) {
    // Slot machine reel spinning sound
    for (uint8_t i = 0; i < 3; i++) {
        play_2000hz(10);
        _delay_ms(5);
        play_1500hz(10);
        _delay_ms(5);
    }
}

void play_win_sound(uint8_t big_win) {
    if (big_win) {
        // Exciting jackpot sound
        play_2000hz(50);
        _delay_ms(20);
        play_2500hz(50);
        _delay_ms(20);
        play_3000hz(100);
        _delay_ms(50);
        play_2500hz(50);
        _delay_ms(20);
        play_3000hz(150);
        _delay_ms(20);
        play_2000hz(50);
        _delay_ms(20);
        play_2500hz(50);
        _delay_ms(20);
        play_3000hz(200);
    } else {
        // Smaller win sound
        play_1500hz(40);
        _delay_ms(20);
        play_2000hz(40);
        _delay_ms(20);
        play_2500hz(80);
        _delay_ms(30);
        play_3000hz(120);
    }
}

void play_lose_sound(void) {
    // Downward wah-wah sound
    play_1000hz(70);
    _delay_ms(10);
    play_750hz(70);
    _delay_ms(10);
    play_500hz(150);
}

void play_game_over_sound(void) {
    // Game over jingle
    play_1000hz(80);
    _delay_ms(20);
    play_750hz(80);
    _delay_ms(20);
    play_500hz(80);
    _delay_ms(100);
    play_750hz(80);
    _delay_ms(20);
    play_500hz(160);
}

bool init_peripherals(void) {
    // Initialize I2C at 400kHz
    i2c_init(I2C_FREQUENCY);
    printf("I2C initialized\r\n");
    
    // Initialize MAX30102
    if (!max30102_init()) {
        printf("Failed to initialize MAX30102 sensor\r\n");
        return false;
    }
    printf("MAX30102 sensor initialized\r\n");
    
    // Configure MAX30102 with default settings
    max30102_led_amplitude_t led_amplitude = {
        .red = 0x1F,  // ~6.4mA
        .ir = 0x1F    // ~6.4mA
    };
    
    if (!max30102_configure(MAX30102_SAMPLE_RATE_100_HZ, 
                           MAX30102_PULSE_WIDTH_411_US,
                           MAX30102_ADC_RANGE_16384_NA,
                           led_amplitude)) {
        printf("Failed to configure MAX30102 sensor\r\n");
        return false;
    }
    
    // Set up external interrupt (INT1 on PD3)
    // Configure PD3 as input with pull-up
    DDRD &= ~(1 << PD3);      // Set PD3 as input
    PORTD |= (1 << PD3);      // Enable pull-up
    
    // Set up INT1 for falling edge detection
    EICRA &= ~(1 << ISC10);   // Clear ISC10
    EICRA |= (1 << ISC11);    // Set ISC11 for falling edge
    EIMSK |= (1 << INT1);     // Enable INT1
    
    // Clear any pending interrupts
    uint8_t int_status_1, int_status_2;
    max30102_read_interrupt_status(&int_status_1, &int_status_2);
    
    return true;
}

// Initialize hardware
void initialize(void) {
    // Initialize LCD
    lcd_init();
    
    init_buzzer();
    
    // Setup button input with internal pull-up
    // Using PD2 (INT0) as the button input pin
    DDRD &= ~(1 << DDD2);  // Set PD2 as input
    PORTD |= (1 << PORTD2); // Enable pull-up resistor
    
    // Initialize UART for debugging
    uart_init();
    if (!init_peripherals()) {
        while (1) {
            // Halt on error
            _delay_ms(1000);
        }
    }
    
    // Setup button interrupt
    setupButtonInterrupt();

    // Initialize the screen
    LCD_setScreen(BLACK);
    
    // Seed the random number generator with ADC noise
    // Enable ADC and set prescaler to 128
    ADCSRA = (1 << ADEN) | (1 << ADPS2) | (1 << ADPS1) | (1 << ADPS0);
    // Select ADC channel 0 (can be any unused analog input)
    ADMUX = 0;
    
    // Do a few readings to seed our random number generator
    for (uint8_t i = 0; i < 16; i++) {
        // Start conversion
        ADCSRA |= (1 << ADSC);
        // Wait for conversion to complete
        while (ADCSRA & (1 << ADSC));
        // Use the least significant bits as they're noisier
        rand_seed = (rand_seed << 1) | (ADC & 0x01);
    }
    
    // Make sure seed is never 0
    if (rand_seed == 0) rand_seed = 0x1234;
    
    // Enable global interrupts
    sei();
    
    // Print debug info
    printf("T&T Slots - Sense the Win\r\n");
    printf("System Initialized\r\n");
    
}

// Setup button interrupt on INT0 (PD2)
void setupButtonInterrupt(void) {
    // Configure INT0 to trigger on falling edge
    EICRA |= (1 << ISC01);
    EICRA &= ~(1 << ISC00);
    
    // Enable INT0 interrupt
    EIMSK |= (1 << INT0);
}

// Display welcome screen
void displayWelcomeScreen(void) {
    LCD_setScreen(BLACK);
    play_welcome_theme();
    
    // Display title
    LCD_drawString(20, 20, "T&T SLOTS", YELLOW, BLACK);
    LCD_drawString(15, 40, "Sense the Win", RED, BLACK);
    
    // Draw a decorative border
    LCD_drawBlock(10, 10, 150, 12, RED);    // Top border
    LCD_drawBlock(10, 110, 150, 112, RED);  // Bottom border
    LCD_drawBlock(10, 10, 12, 112, RED);    // Left border
    LCD_drawBlock(148, 10, 150, 112, RED);  // Right border
    
    // Display instructions
    LCD_drawString(15, 70, "Press Button", WHITE, BLACK);
    LCD_drawString(25, 85, "to Start", WHITE, BLACK);
    
    // Wait for a moment before proceeding
    _delay_ms(2000);
    
    // Transition to next state
    currentState = STATE_PRESS_BUTTON;
}

// Display prompt to press the button
void displayPressButtonPrompt(void) {
    static uint8_t promptDisplayed = 0;
    
    if (!promptDisplayed) {
        LCD_setScreen(BLACK);
        
        // Draw header
        LCD_drawString(15, 15, "READY TO PLAY?", GREEN, BLACK);
        
        // Draw button prompt
        LCD_drawString(5, 40, "Press the Button (gently)", WHITE, BLACK);
        LCD_drawString(20, 55, "to try your luck!", WHITE, BLACK);
        
        // Draw a simple button graphic
        LCD_drawBlock(60, 70, 100, 90, BLUE);
        LCD_drawString(67, 78, "PLAY", WHITE, BLUE);
        
        // Draw a heart symbol
        LCD_drawDisk(80, 105, 10, RED);
        LCD_drawDisk(90, 105, 10, RED);
        LCD_drawBlock(80, 105, 90, 115, RED);
        LCD_drawBlock(75, 100, 95, 105, BLACK);
        LCD_drawBlock(85, 115, 86, 116, RED);
        
        promptDisplayed = 1;
    }
    
    // Simple animation for the heart
    if (animationFrame % 10 == 0) {
        // Make heart "beat" occasionally
        LCD_drawDisk(80, 105, 11, RED);
        LCD_drawDisk(90, 105, 11, RED);
        LCD_drawBlock(80, 105, 90, 116, RED);
        LCD_drawBlock(75, 100, 95, 105, BLACK);
        LCD_drawBlock(85, 116, 86, 117, RED);
    } else if (animationFrame % 10 == 1) {
        // Return to normal size
        LCD_drawDisk(80, 105, 10, RED);
        LCD_drawDisk(90, 105, 10, RED);
        LCD_drawBlock(80, 105, 90, 115, RED);
        LCD_drawBlock(75, 100, 95, 105, BLACK);
        LCD_drawBlock(85, 115, 86, 116, RED);
    }
    
    animationFrame++;
    _delay_ms(50);
    
    // Reset if we change states
    if (currentState != STATE_PRESS_BUTTON) {
        promptDisplayed = 0;
    }
}

// Display measuring heart rate prompt
void displayMeasuringPrompt(void) {
    static uint8_t lastHeartRateDisplayed = 0;
//    printf("measuring1\n");
    
    // First, clear screen and setup initial display
    if (measureAnime == 0) {
        measureAnime = 1;
        LCD_setScreen(BLACK);
        LCD_drawString(5, 15, "CHARGING UP YOUR WIN...", CYAN, BLACK);
        LCD_drawString(10, 70, "Keep finger on button top...", WHITE, BLACK);
        LCD_drawString(10, 85, "and press more times!", WHITE, BLACK);
    }
    

    
//    printf("measuring3\n");
    
    // Draw progress animation
    switch(animationFrame % 4) {
        case 0:
            LCD_drawString(70, 40, "|", WHITE, BLACK);
//            play_measuring_sound();
            break;
        case 1:
            LCD_drawString(70, 40, "/", WHITE, BLACK);
            break;
        case 2:
            LCD_drawString(70, 40, "-", WHITE, BLACK);
//            play_measuring_sound();
            break;
        case 3:
            LCD_drawString(70, 40, "\\", WHITE, BLACK);
            break;
    }
    
    // Update animation frame
    animationFrame++;
    
//    printf("measuring4\n");
    
    // Timing for animation
    _delay_ms(250);
}

// Display spinning wheels prompt
void displaySpinningPrompt(void) {
    LCD_setScreen(BLACK);
    
    // Draw header
    LCD_drawString(30, 15, "SPINNING!", MAGENTA, BLACK);
    
    if (animationFrame % 2 == 0) {
        play_spinning_sound();
    }
    
    // Display heart rate info
//    char hrBuffer[20];
//    sprintf(hrBuffer, "Your HR: %3d BPM", heartRate);
//    LCD_drawString(20, 30, hrBuffer, WHITE, BLACK);
    
    // Draw spinning wheels
    char symbols[4] = {'7', '$', '#', '@'};
    
    for (uint8_t wheel = 0; wheel < 3; wheel++) {
        // Calculate position for each wheel
        uint8_t x = 40 + wheel * 40;
        
        // Draw wheel border
        LCD_drawBlock(x - 10, 50, x + 10, 90, BLUE);
        
        // Draw current symbol
        char symbol = symbols[custom_rand_range(4)];
        LCD_drawChar(x - 3, 65, symbol, WHITE, BLUE);
    }
    
    // Update animation frame
    animationFrame++;
    rand_seed ^= (uint16_t)TCNT0;
    
    // Slow down animation
    _delay_ms(200);
}

// Display result screen
void displayResultScreen(uint8_t win) {
    LCD_setScreen(BLACK);
    char symbols[4] = {'7', '$', '#', '@'};
    
    if (win) {
        uint8_t jackpot = (custom_rand_range(10) < 5);  // 20% chance of jackpot on win
        
        play_win_sound(jackpot);
        
        // Win screen
        if (jackpot) {
            LCD_drawString(30, 10, "JACKPOT!!", YELLOW, BLACK);
            LCD_drawString(20, 30, "BIG WIN!!!", GREEN, BLACK);
        } else {
            LCD_drawString(30, 10, "YOU WIN!", YELLOW, BLACK);
            LCD_drawString(20, 30, "GOOD LUCK!", GREEN, BLACK);
        }
        
        for (uint8_t wheel = 0; wheel < 3; wheel++) {
            // Calculate position for each wheel
            uint8_t x = 40 + wheel * 40;

            // Draw wheel border
            LCD_drawBlock(x - 10, 65, x + 10, 90, BLUE);

            // Draw current symbol
            char symbol = symbols[jackpot];
            LCD_drawChar(x - 3, 80, symbol, WHITE, BLUE);
        }
    } else {
        play_lose_sound();
        // Lose screen
        LCD_drawString(30, 10, "TRY AGAIN", RED, BLACK);
        LCD_drawString(15, 30, "Better luck", WHITE, BLACK);
        LCD_drawString(20, 45, "next time!", WHITE, BLACK);
        
        
    
        for (uint8_t wheel = 0; wheel < 3; wheel++) {
            // Calculate position for each wheel
            uint8_t x = 40 + wheel * 40;

            // Draw wheel border
            LCD_drawBlock(x - 10, 65, x + 10, 90, BLUE);

            // Draw current symbol
            char symbol = symbols[custom_rand_range(4)];
            LCD_drawChar(x - 3, 80, symbol, WHITE, BLUE);
        }
    }
    
    // Wait for a moment
    _delay_ms(3000);
    play_game_over_sound();
    _delay_ms(250);
    
    // Return to welcome screen
    currentState = STATE_WELCOME;
}


// Determine win odds based on heart rate
uint8_t determineWinOdds() {
    // Win logic according to SRS-03:
    // If HR is low, increase odds of winning
    // If HR is high, decrease odds to elongate play
    
    // Define heart rate thresholds
    #define LOW_HR_THRESHOLD 80
    #define HIGH_HR_THRESHOLD 120
    
    uint8_t winPercentage = 100;
    
    printf("HR used to determine odd: %u\n", heartRate);
    
    if (heartRate < LOW_HR_THRESHOLD) {
        // Low heart rate - guarantee win 
        winPercentage = 100;
    } else if (heartRate > HIGH_HR_THRESHOLD) {
        // High heart rate - lower odds (down to 5%)
        winPercentage = 20 - ((heartRate - HIGH_HR_THRESHOLD) / 10);
        if (winPercentage < 5) winPercentage = 5;
    } else {
        // Medium heart rate - medium odds (10-20%)
        winPercentage = 50 - ((heartRate - LOW_HR_THRESHOLD) / 2);
    }
    
    printf("Win odds: %u%%\r\n", winPercentage);
    return winPercentage;
}

// Button interrupt handler
ISR(INT0_vect) {
    // Debounce
    _delay_ms(10);
    
//    // Check if button is still pressed
//    if (!(PIND & (1 << PIND2))) {
//        // Button was pressed
//        buttonPressed = 1;
//        printf("pressing\n");
//        // If we're in PRESS_BUTTON state, move to MEASURING state
//        if (currentState == STATE_PRESS_BUTTON) {
//            currentState = STATE_MEASURING;
//            animationFrame = 0;
//        }
//    }
    
    // Button was pressed
    printf("button pressed\n");
    if (currentState == STATE_PRESS_BUTTON) {
        play_button_press();
        animationFrame = 0;
        currentState = STATE_MEASURING;  
        
    }
}



// Heart rate sensor interrupt handler (INT1 - PD3)
ISR(INT1_vect) {
    if (max30102_read_interrupt_status(&int_status_1, &int_status_2)) {
                if (int_status_1 & MAX30102_INT_A_FULL) {
                    // printf("INT detected via polling: 0x%02X\r\n", int_status_1);
                    
                    // Read FIFO pointers to determine how many samples to read
                    if (max30102_read_fifo_ptrs(&write_ptr, &read_ptr, &overflow)) {
                        // Calculate number of samples to read
                        if (write_ptr >= read_ptr) {
                            sample_count = write_ptr - read_ptr;
                        } else {
                            sample_count = 32 - read_ptr + write_ptr;  // FIFO is 32 samples deep
                        }
                        
                        // Cap sample count to buffer size
                        if (sample_count > SAMPLE_COUNT) {
                            sample_count = SAMPLE_COUNT;
                        }
                        
                        // Only process data if we have enough samples
                        if (sample_count >= 5) {
                            // Read samples from FIFO
                            sample_count = max30102_read_fifo_samples(samples, sample_count);
                            
                            // Process samples to calculate heart rate and SpO2
                            if (max30102_calculate_hr_spo2(samples, sample_count, &result)) {
                                
                                heartRateReady = result.hr_valid;
                                
                                // Print heart rate and validity
                                if (heartRateReady) {
//                                    printf("%ld\tValid\t\t\n", result.heart_rate);
                                    heartRate = result.heart_rate;
                                } else {
//                                    printf("--\tInvalid\t\t\n");
                                }

                            }
                        }
                    }
                }
            }
    
    // Update RNG seed on each interrupt for more randomness
    
}
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
int main(void) {
    // Initialize hardware
    initialize();
    
    // Start with welcome screen
    currentState = STATE_WELCOME;
    uint32_t loop_count = 0;
    
    // Main loop
    while (1) {   
        rand_seed ^= (uint16_t)TCNT0;
        // State machine
        switch (currentState) {
            case STATE_WELCOME:
                displayWelcomeScreen();
                break;
                
            case STATE_PRESS_BUTTON:
                displayPressButtonPrompt();
                break;
                
            case STATE_MEASURING:
                displayMeasuringPrompt();
       
                if (heartRateReady) {
                    printf("HR=%u BPM\r\n", heartRate);
                    
                    // Button released, determine odds and start spinning
                    currentState = STATE_SPINNING;
                    animationFrame = 0;
                }
                break;
                
            case STATE_SPINNING:
                displaySpinningPrompt();
                
                // Simulate spinning for 3 seconds, then show result
                static uint8_t spinCount = 0;
                spinCount++;
                
                if (spinCount > 15) {  // ~3 seconds (15 * 200ms)
                    spinCount = 0;
                    
                    // Determine win based on heart rate
                    uint8_t winPercentage = determineWinOdds();
                    uint8_t randomValue = custom_rand_range(100);
                    uint8_t win = (randomValue < winPercentage);
                    
                    // Show result
                    currentState = STATE_RESULT;
                    displayResultScreen(win);
                }
                break;
                
            case STATE_RESULT:
                // This state is handled by displayResultScreen
                // which automatically transitions back to welcome
                break;
                
            default:
                // In case of unknown state, reset to welcome
                currentState = STATE_WELCOME;
                break;
        }
    }
    
    return 0;
}

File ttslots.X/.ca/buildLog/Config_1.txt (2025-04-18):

make -f nbproject/Makefile-Config_1.mk SUBPROJECTS= .clean-conf
make[1]: Entering directory 'C:/Users/24112/OneDrive - PennO365/Penn/ESE 3500/ttslots/ttslots.X'
rm -f  -r .ca/build/Config_1/production
rm -f  -r .ca/dist/Config_1/production
make[1]: Leaving directory 'C:/Users/24112/OneDrive - PennO365/Penn/ESE 3500/ttslots/ttslots.X'
[32mCLEAN SUCCESSFUL (total time: 101ms)[0m
make -f nbproject/Makefile-Config_1.mk SUBPROJECTS= .build-conf
make  -f nbproject/Makefile-Config_1.mk .ca/dist/Config_1/production/ttslots.X.production.hex
make[2]: Entering directory 'C:/Users/24112/OneDrive - PennO365/Penn/ESE 3500/ttslots/ttslots.X'
"C:\Program Files\Microchip\xc8\v3.00\bin\xc8-cc.exe"  -mcpu=ATmega328PB -c  -x c -D__ATmega328PB__   -mdfp="C:/Users/24112/.mchp_packs/Microchip/ATmega_DFP/3.1.264/xc8"  -Wl,--gc-sections -O1 -ffunction-sections -fdata-sections -fshort-enums -fno-common -funsigned-char -funsigned-bitfields -Wall -DXPRJ_Config_1=Config_1    -gdwarf-3 -mno-const-data-in-progmem     -MD -MP -MF ".ca/build/Config_1/production/ST7735.o.d" -MT ".ca/build/Config_1/production/ST7735.o.d" -MT .ca/build/Config_1/production/ST7735.o -o .ca/build/Config_1/production/ST7735.o ST7735.c 
make[2]: Leaving directory 'C:/Users/24112/OneDrive - PennO365/Penn/ESE 3500/ttslots/ttslots.X'
make[2]: Entering directory 'C:/Users/24112/OneDrive - PennO365/Penn/ESE 3500/ttslots/ttslots.X'
"C:\Program Files\Microchip\xc8\v3.00\bin\xc8-cc.exe"  -mcpu=ATmega328PB -c  -x c -D__ATmega328PB__   -mdfp="C:/Users/24112/.mchp_packs/Microchip/ATmega_DFP/3.1.264/xc8"  -Wl,--gc-sections -O1 -ffunction-sections -fdata-sections -fshort-enums -fno-common -funsigned-char -funsigned-bitfields -Wall -DXPRJ_Config_1=Config_1    -gdwarf-3 -mno-const-data-in-progmem     -MD -MP -MF ".ca/build/Config_1/production/uart.o.d" -MT ".ca/build/Config_1/production/uart.o.d" -MT .ca/build/Config_1/production/uart.o -o .ca/build/Config_1/production/uart.o uart.c 
make[2]: Leaving directory 'C:/Users/24112/OneDrive - PennO365/Penn/ESE 3500/ttslots/ttslots.X'
make[2]: Entering directory 'C:/Users/24112/OneDrive - PennO365/Penn/ESE 3500/ttslots/ttslots.X'
"C:\Program Files\Microchip\xc8\v3.00\bin\xc8-cc.exe"  -mcpu=ATmega328PB -c  -x c -D__ATmega328PB__   -mdfp="C:/Users/24112/.mchp_packs/Microchip/ATmega_DFP/3.1.264/xc8"  -Wl,--gc-sections -O1 -ffunction-sections -fdata-sections -fshort-enums -fno-common -funsigned-char -funsigned-bitfields -Wall -DXPRJ_Config_1=Config_1    -gdwarf-3 -mno-const-data-in-progmem     -MD -MP -MF ".ca/build/Config_1/production/LCD_GFX.o.d" -MT ".ca/build/Config_1/production/LCD_GFX.o.d" -MT .ca/build/Config_1/production/LCD_GFX.o -o .ca/build/Config_1/production/LCD_GFX.o LCD_GFX.c 
make[2]: Leaving directory 'C:/Users/24112/OneDrive - PennO365/Penn/ESE 3500/ttslots/ttslots.X'
make[2]: Entering directory 'C:/Users/24112/OneDrive - PennO365/Penn/ESE 3500/ttslots/ttslots.X'
"C:\Program Files\Microchip\xc8\v3.00\bin\xc8-cc.exe"  -mcpu=ATmega328PB -c  -x c -D__ATmega328PB__   -mdfp="C:/Users/24112/.mchp_packs/Microchip/ATmega_DFP/3.1.264/xc8"  -Wl,--gc-sections -O1 -ffunction-sections -fdata-sections -fshort-enums -fno-common -funsigned-char -funsigned-bitfields -Wall -DXPRJ_Config_1=Config_1    -gdwarf-3 -mno-const-data-in-progmem     -MD -MP -MF ".ca/build/Config_1/production/i2c.o.d" -MT ".ca/build/Config_1/production/i2c.o.d" -MT .ca/build/Config_1/production/i2c.o -o .ca/build/Config_1/production/i2c.o i2c.c 
make[2]: Leaving directory 'C:/Users/24112/OneDrive - PennO365/Penn/ESE 3500/ttslots/ttslots.X'
[31mIn file included from ST7735.c:16:0:
c:\program files\microchip\xc8\v3.00\avr\avr\include\util\delay.h:92:3: warning: #warning "F_CPU not defined for <util/delay.h>" [-Wcpp]
make[2]: Entering directory 'C:/Users/24112/OneDrive - PennO365/Penn/ESE 3500/ttslots/ttslots.X'
 # warning "F_CPU not defined for <util/delay.h>"
   ^
In file included from uart.c:2:0:
uart.h:43:6: warning: #warning "F_CPU not defined. Defaulting to 16MHz" [-Wcpp]
     #warning "F_CPU not defined. Defaulting to 16MHz"
      ^
LCD_GFX.c: In function 'LCD_drawChar':
LCD_GFX.c:54:20: warning: suggest parentheses around comparison in operand of '&' [-Wparentheses]
     if ((pixels>>j)&1==1){
                    ^
i2c.c:99:13: warning: 'i2c_wait' defined but not used [-Wunused-function]
 static bool i2c_wait(uint16_t timeout_ms) {
             ^
i2c.c:48:13: warning: 'delay_ms' defined but not used [-Wunused-function]
 static void delay_ms(uint16_t ms) {
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

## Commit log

2025-04-04 i2c skeleton
2025-04-06 i2c updated
2025-04-07 i2c de bug
2025-04-11 i2c part fix
2025-04-11 dedicated i2c debug file
2025-04-11 got hr in new driver
2025-04-16 i2c part ingetration
2025-04-16 i2c int progress
2025-04-16 i2c int polling
2025-04-17 optimized mem
    [Config_1.txt, Config_2.txt]
2025-04-18 button logic
2025-04-18 improved animation
    [Config_1.txt, Config_2.txt]
